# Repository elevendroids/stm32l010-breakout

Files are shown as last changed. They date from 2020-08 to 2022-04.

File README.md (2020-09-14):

# STM32L010 Breakout Board (Rev. B)

Small MCU board designed primarly for the STM32L010K8T6 ARM Cortex-M0+ microcontroller: [Datasheet](https://www.st.com/resource/en/datasheet/stm32l010k8.pdf)

Can also be used with other pin-compatible STM32 MCUs in LQFP-32 package:
- Most of the STM32L0 family
- STM32L4x2 (ARM Cortex-M4)

## Features

- minimal subset of components, no power regulation (important when playing with low power apps)
- optional LSE crystal, if not used its GPIO pins can be connected to the user header by soldering relevant 0R resistors (see schematic)
- two buffered user LEDs, connected to the header - no reserved GPIOs
- reset button
- standard 0.05" pitch SWD programming header, SWD signals also present on the pin headers

Designed in KiCad 5.1.6

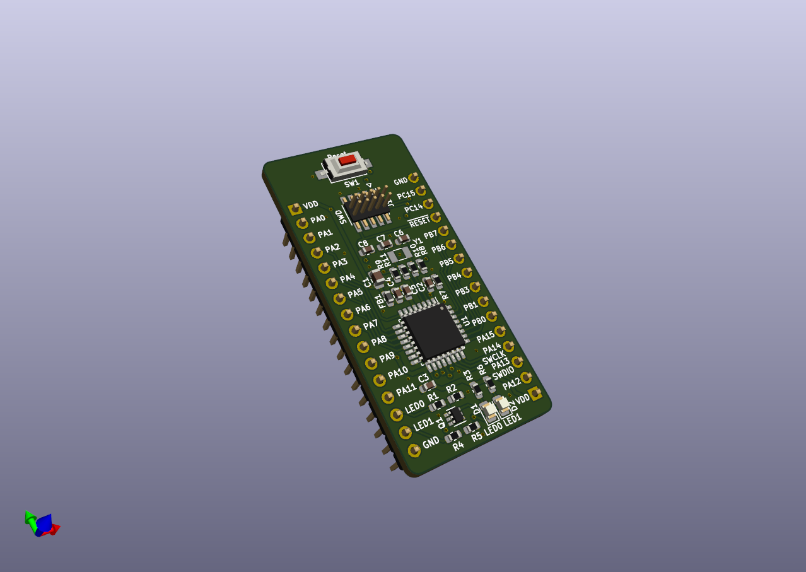
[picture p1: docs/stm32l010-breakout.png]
PCB Render


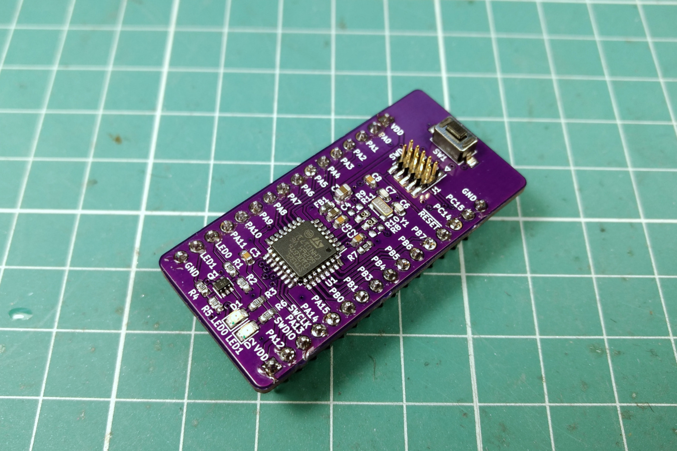
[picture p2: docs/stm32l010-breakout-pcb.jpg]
Prototype


Schematic: [PDF](docs/stm32l010-breakout.pdf)

License: [CC BY-SA 4.0](https://creativecommons.org/licenses/by-sa/4.0/)

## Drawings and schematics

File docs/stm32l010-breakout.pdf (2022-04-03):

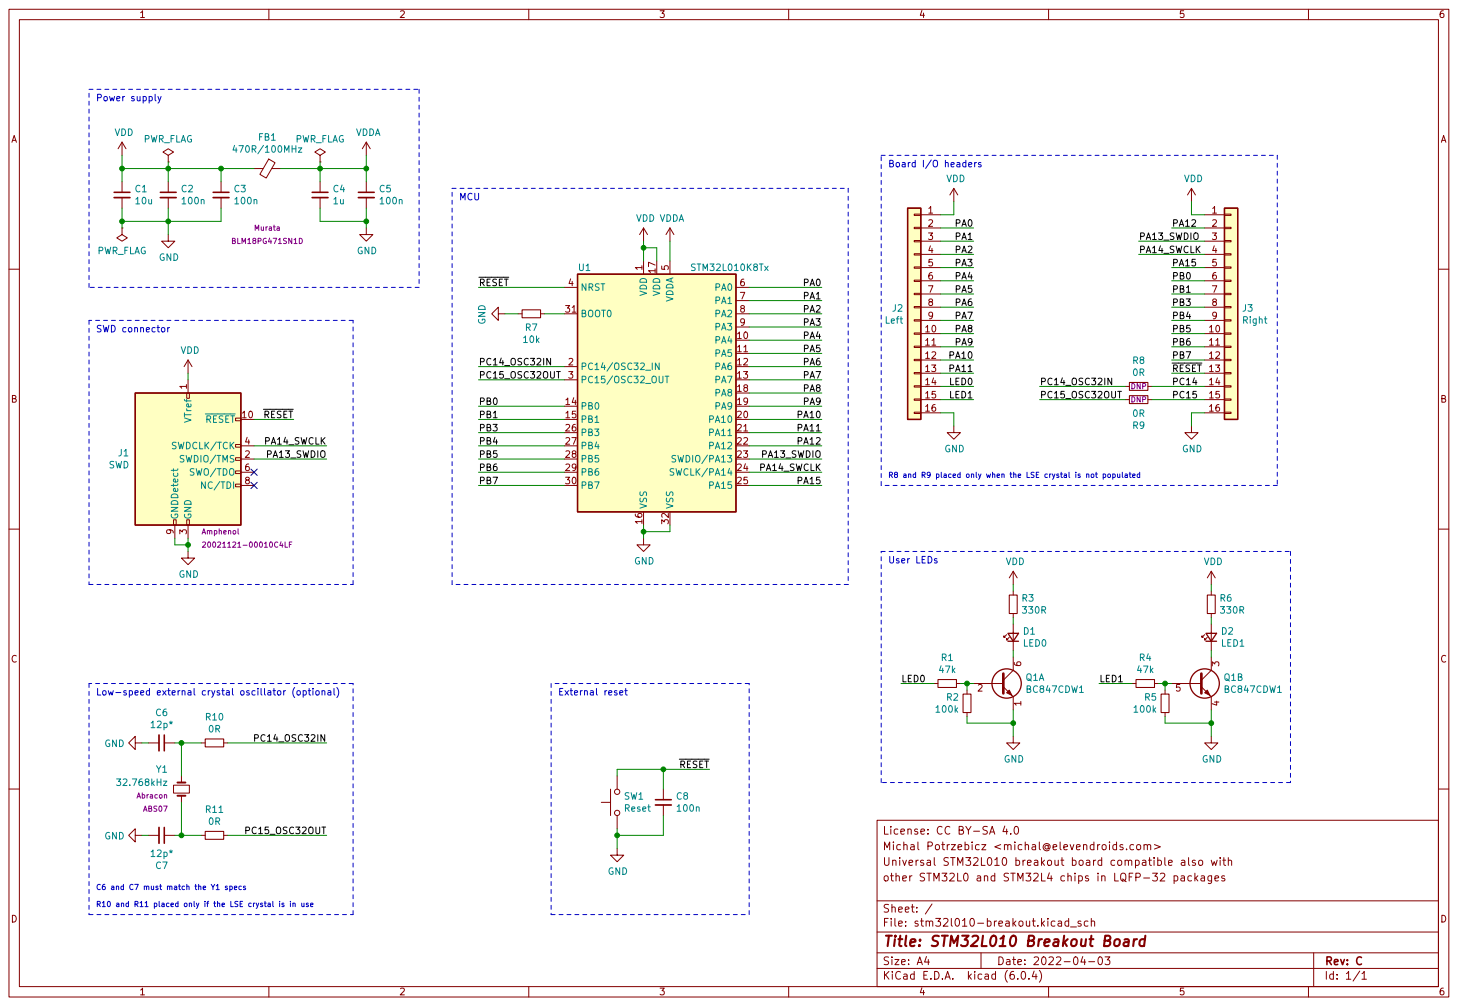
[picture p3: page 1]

1 PA4 10 PA5 11 PA6 12 PA7 13 PB0 14 PB1 15 VSS 16 VDD 17 PA8 18 PA9 19 PC14/OSC32_IN 2 PA10 20 PA11 21 PA12 22 SWDIO/PA13 23 SWCLK/PA14 24 PA15 25 PB3 26 PB4 27 PB5 28 PB6 29 PC15/OSC32_OUT 3 PB7 30 BOOT0 31 VSS 32 NRST 4 VDDA

3 SWDCLK/TCK 4 SWO/TDO 6 NC/TDI 8 GNDDetect 9

R8 and R9 placed only when the LSE crystal is not populated

Michal Potrzebicz <michal@elevendroids.com>
Universal STM32L010 breakout board compatible also with
File: stm32l010-breakout.kicad_sch Sheet: / other STM32L0 and STM32L4 chips in LQFP-32 packages

Id: 1/1 Title: STM32L010 Breakout Board

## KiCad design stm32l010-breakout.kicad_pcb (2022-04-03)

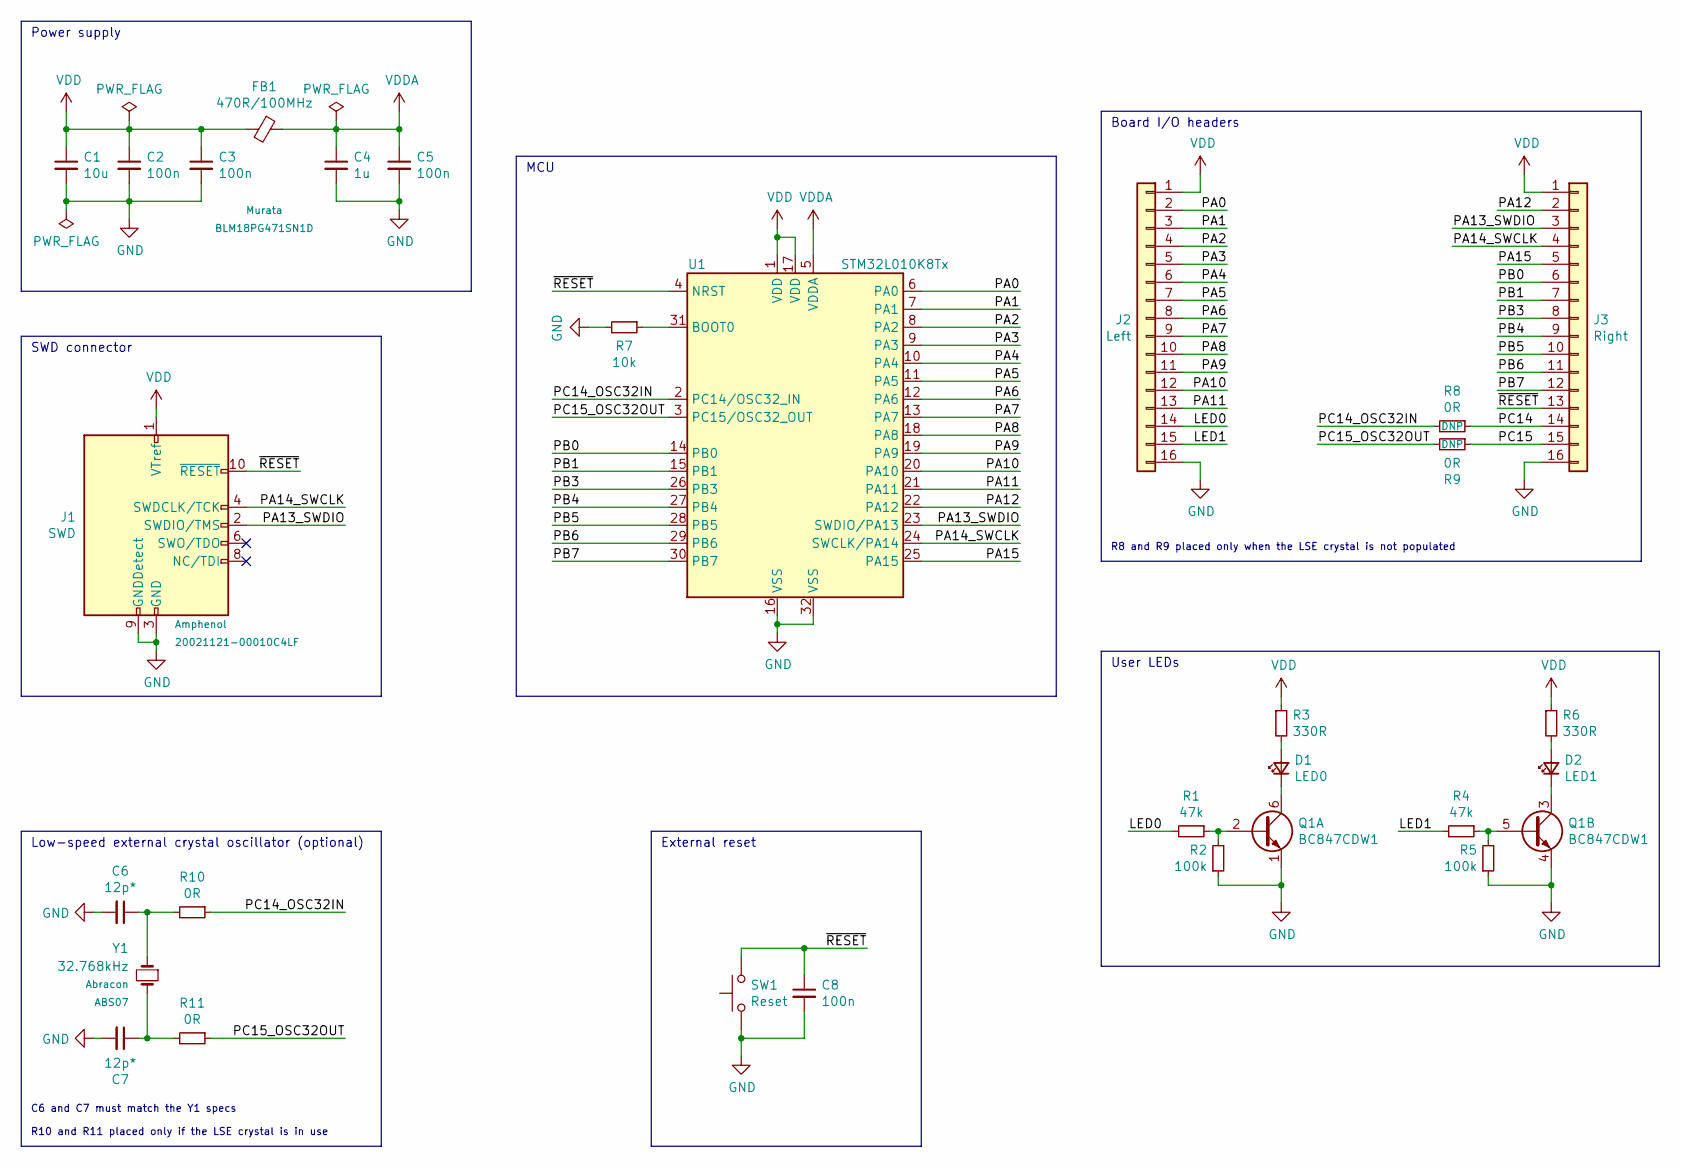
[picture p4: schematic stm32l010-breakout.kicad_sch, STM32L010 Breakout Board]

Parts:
C1: 10u; C_0805_2012Metric
C2, C3, C5, C8: 100n; C_0603_1608Metric
C4: 1u; C_0603_1608Metric
C6, C7: 12p*; C_0603_1608Metric
D1: LED0; LED_0805_2012Metric
D2: LED1; LED_0805_2012Metric
FB1: 470R/100MHz; L_0603_1608Metric; MPN BLM18PG471SN1D
J1: SWD; PinHeader_2x05_P1.27mm_Vertical_SMD; MPN 20021121-00010C4LF
J2: Left; PinHeader_1x16_P2.54mm_Vertical
J3: Right; PinHeader_1x16_P2.54mm_Vertical
Q1: BC847CDW1; SOT-363_SC-70-6
R1, R4: 47k; R_0603_1608Metric
R2, R5: 100k; R_0603_1608Metric
R3, R6: 330R; R_0603_1608Metric
R7: 10k; R_0603_1608Metric
R8, R9, R10, R11: 0R; R_0603_1608Metric
SW1: Reset; SW_SPST_CK_RS282G05A3
U1: STM32L010K8Tx; LQFP-32_7x7mm_P0.8mm; MPN STM32L010K8T6
Y1: 32.768kHz; Crystal_SMD_3215-2Pin_3.2x1.5mm; MPN ABS07

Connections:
/LED0: J2.14, R1.2
/LED1: J2.15, R4.2
/PA0: J2.2, U1.6 (PA0)
/PA1: J2.3, U1.7 (PA1)
/PA2: J2.4, U1.8 (PA2)
/PA3: J2.5, U1.9 (PA3)
/PA4: J2.6, U1.10 (PA4)
/PA5: J2.7, U1.11 (PA5)
/PA6: J2.8, U1.12 (PA6)
/PA7: J2.9, U1.13 (PA7)
/PA8: J2.10, U1.18 (PA8)
/PA9: J2.11, U1.19 (PA9)
/PA10: J2.12, U1.20 (PA10)
/PA11: J2.13, U1.21 (PA11)
/PA12: J3.2, U1.22 (PA12)
/PA13_SWDIO: J1.2 (SWDIO/TMS), J3.3, U1.23 (SWDIO/PA13)
/PA14_SWCLK: J1.4 (SWDCLK/TCK), J3.4, U1.24 (SWCLK/PA14)
/PA15: J3.5, U1.25 (PA15)
/PB0: J3.6, U1.14 (PB0)
/PB1: J3.7, U1.15 (PB1)
/PB3: J3.8, U1.26 (PB3)
/PB4: J3.9, U1.27 (PB4)
/PB5: J3.10, U1.28 (PB5)
/PB6: J3.11, U1.29 (PB6)
/PB7: J3.12, U1.30 (PB7)
/PC14: J3.14, R8.1
/PC14_OSC32IN: R8.2, R10.1, U1.2 (PC14/OSC32_IN)
/PC15: J3.15, R9.1
/PC15_OSC32OUT: R9.2, R11.1, U1.3 (PC15/OSC32_OUT)
/~RESET: C8.1, J1.10 (~RESET), J3.13, SW1.2, U1.4 (NRST)
GND: C1.2, C2.2, C3.2, C4.2, C5.2, C6.2, C7.2, C8.2, J1.3 (GND), J1.5 (GND), J1.9 (GNDDetect), J2.16, J3.16, Q1.1 (E1), Q1.4 (E2), R2.1, R5.1, R7.2, SW1.1, U1.16 (VSS), U1.32 (VSS)
unnamed: C6.1, R10.2, Y1.1
unnamed: C7.1, R11.2, Y1.2
unnamed: D1.1 (K), Q1.6 (C1)
unnamed: D1.2 (A), R3.2
unnamed: D2.1 (K), Q1.3 (C2)
unnamed: D2.2 (A), R6.2
unnamed: Q1.2 (B1), R1.1, R2.2
unnamed: Q1.5 (B2), R4.1, R5.2
unnamed: R7.1, U1.31 (BOOT0)
VDD: C1.1, C2.1, C3.1, FB1.2, J1.1 (VTref), J2.1, J3.1, R3.1, R6.1, U1.1 (VDD), U1.17 (VDD)
VDDA: C4.1, C5.1, FB1.1, U1.5 (VDDA)

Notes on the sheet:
C6 and C7 must match the Y1 specs R10 and R11 placed only if the LSE crystal is in use
Power supply
R8 and R9 placed only when the LSE crystal is not populated
SWD connector
External reset
Low-speed external crystal oscillator (optional)
MCU
Board I/O headers
User LEDs

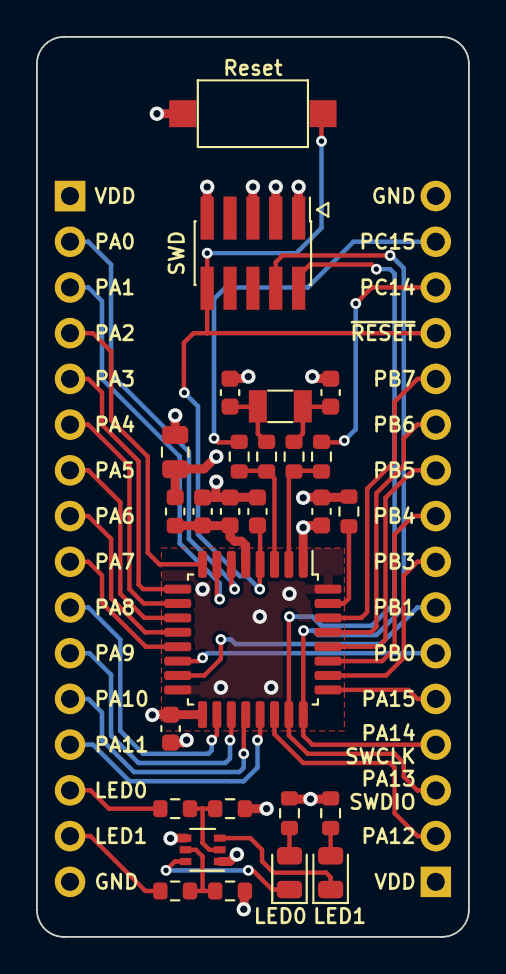
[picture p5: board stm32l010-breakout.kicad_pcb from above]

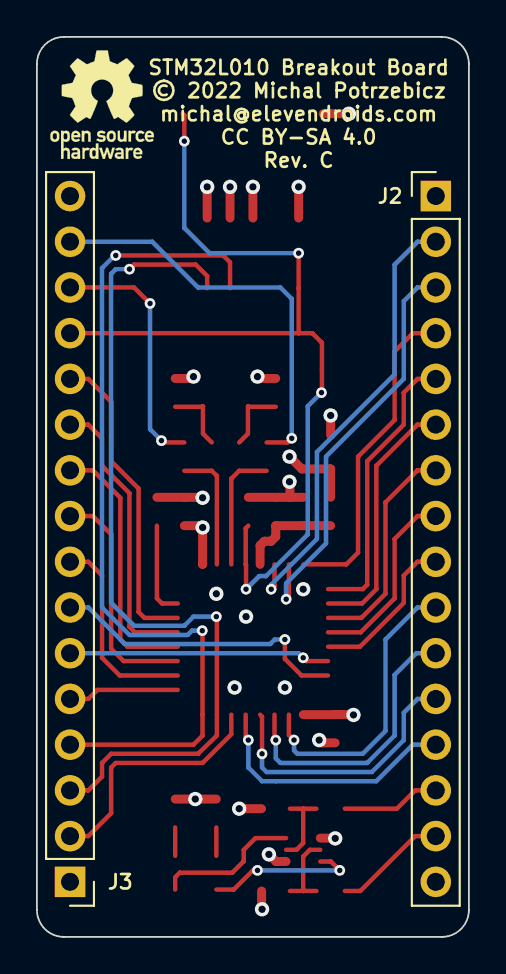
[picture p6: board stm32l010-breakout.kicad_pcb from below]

Board: 4 copper layers, 24.0 x 50.0 mm, 29 parts (2 on the bottom side), 42 nets.

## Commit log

2020-07-31 Initial commit
    Prototypes ordered from OSHPark
    [stm32l010-breakout.kicad_pcb, stm32l010-breakout.sch]
2020-08-05 Schematic cleanup, partial re-layout
    - Changed the PCB size to 25x50mm
    - Use 0R resistors for LSE oscillator/GPIO selection
    - Schematic cleanup
    [stm32l010-breakout.kicad_pcb, stm32l010-breakout.sch]
2020-08-05 Schematic PDF
2020-08-14 Finished laying out Revision B
    [stm32l010-breakout.kicad_pcb, stm32l010-breakout.sch]
2020-08-14 Updated schematic PDF
2020-08-14 Fixed copper pour settings, small tweaks
    [stm32l010-breakout.kicad_pcb]
2020-08-15 Rotated the SWD connector, moved LED buffer to the front layer
    [stm32l010-breakout.kicad_pcb]
2020-08-15 More PCB tweaks
    [stm32l010-breakout.kicad_pcb, stm32l010-breakout.sch]
2020-08-16 Finished (hopefully) layout for the Rev. B
    [stm32l010-breakout.kicad_pcb]
2020-08-17 Added readme, license and a pcb render
2020-09-02 Added interactive BOM
2020-09-14 Added photo of the first OSHPark prototype
2020-09-15 Schematic cleanup
    [stm32l010-breakout.sch]
2020-11-11 Updated STM32L010 symbol
    [stm32l010-breakout.sch]
2020-11-11 Synced with library changes
    [stm32l010-breakout.sch]
2021-04-07 Schematic update due to STM32L010 library changes
    [stm32l010-breakout.sch]
2021-04-07 Updated PDF schematic
2022-04-03 Revision C with a 4 layer PCB, initial commit
    [stm32l010-breakout.kicad_pcb, stm32l010-breakout.kicad_sch, stm32l010-breakout.sch]

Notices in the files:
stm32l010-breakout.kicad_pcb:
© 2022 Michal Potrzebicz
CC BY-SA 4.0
